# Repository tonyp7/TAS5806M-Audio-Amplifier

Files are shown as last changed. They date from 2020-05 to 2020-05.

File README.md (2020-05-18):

# TAS5806M Audio Amplifier

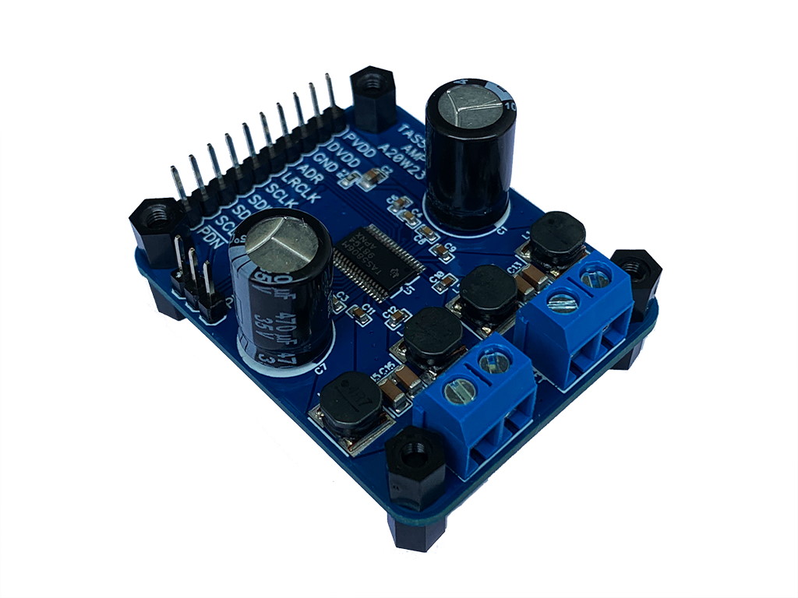
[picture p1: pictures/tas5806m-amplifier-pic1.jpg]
Amplifier board


This repository contains hardware to create a fully fledged TAS5806M 23-W, I2S digital Input, stereo, closed-loop Class-D audio
amplifier.
In addition, it contains example software for Espressif's ESP32 to create a bluetooth audio speaker. Any micro-controller capable of I2S and I2C will be able to control the board, ESP32 is picked here due to its popularity and large documentation.

# Repository structure

* hardware: contains the PCB, schematics and BOM for the physical audio amplfiier board
* software: contains code examples to interface with the board

# License

Hardware and software is free and open source, published under the MIT license.

# Compatibility with TAS5805M

Both amplifiers are the same but in different packages allowing for different maximum power output. They share the same I2C interface and registers and as such the code included in this repository is compatible with TAS5805M audio amplifier. [See here the comment from TI on this topic](http://e2e.ti.com/support/audio/f/6/t/812496?TAS5805M-comparing-to-TAS5806M).

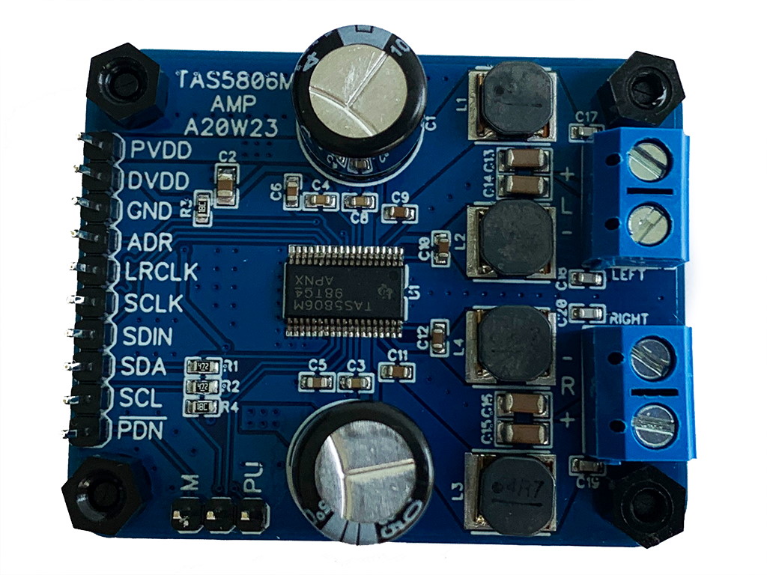
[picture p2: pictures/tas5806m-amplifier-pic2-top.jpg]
Amplifier board top


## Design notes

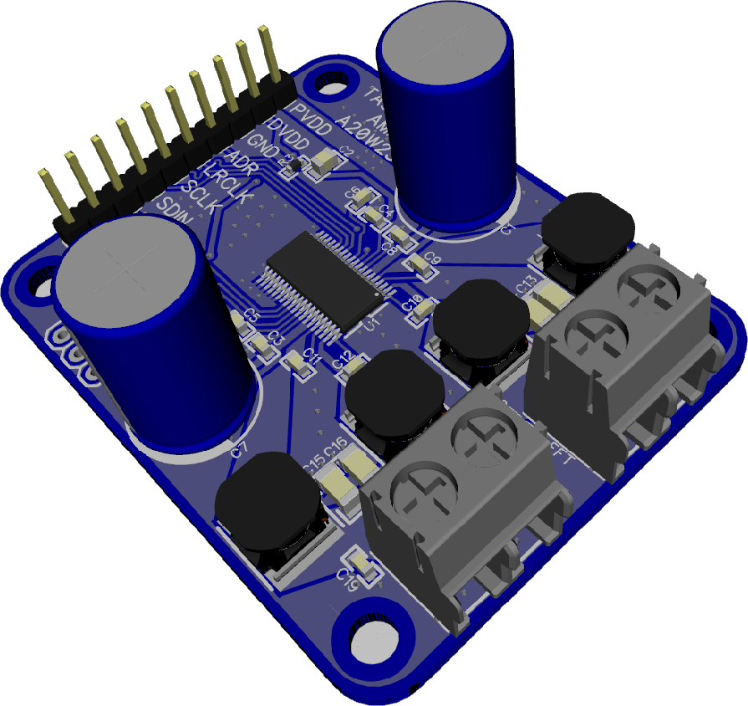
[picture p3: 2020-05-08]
hardware/pcb/3d-pcp-render.png

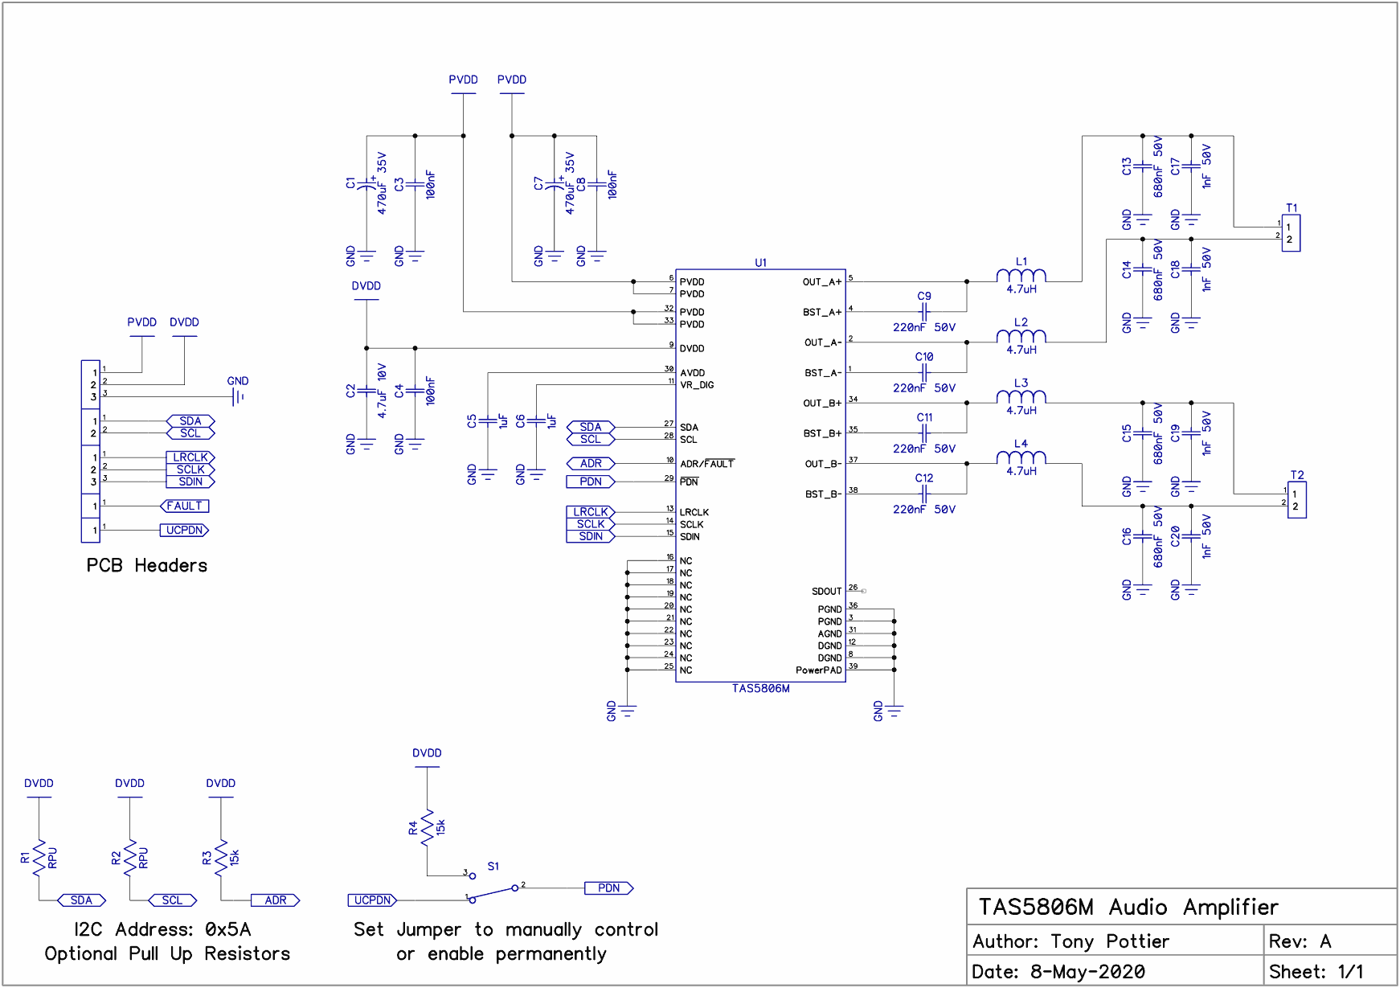
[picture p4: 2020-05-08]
hardware/schematics/tas5806m-schematics.png

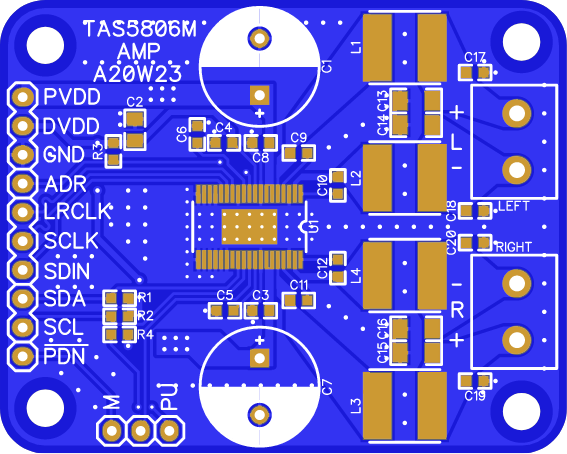
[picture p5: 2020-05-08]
hardware/pcb/pcb-render-top.png

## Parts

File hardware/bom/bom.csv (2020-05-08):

RefDes | Quantity | Manufacturer Part Number | Manufacturer | Description | Mounting | Package
C1, C7 | 2 | EEU-FR1V471 | Panasonic | CAP ALUM 470UF 20% 35V RADIAL | THT
C2 | 1 | CL21A475KPFNNNE | Samsung | CAP CER 4.7UF 10V X5R 0805 | SMT | 0805
C3, C4, C8 | 3 | CC0603KRX7R9BB104 | Yageo | CAP CER 0.1UF 50V X7R 0603 | SMT | 0603
C5, C6 | 2 | CC0603KRX5R6BB105 | Yageo | CAP CER 1UF 10V X5R 0603 | SMT | 0603
C9, C10, C11, C12 | 4 | CC0603KRX7R9BB224 | Yageo | CAP CER 0.22UF 50V X7R 0603 | SMT | 0603
C13, C14, C15, C16 | 4 | CC1206KKX7R9BB684 | Yageo | CAP CER 0.68UF 50V X7R 1206 | SMT | 1206
C17, C18, C19, C20 | 4 | CC0603JRNPO9BN102 | Yageo | CAP CER 1000PF 50V C0G/NPO 0603 | SMT | 0603
L1, L2, L3, L4 | 4 | 1255AY-4R7M=P3 | Murata | FIXED IND 4.7UH 4.5A 27.6 MOHM | SMT
R1, R2 | 2 | RC0603FR-074K7L | Yageo | RES SMD 4.7K OHM 1% 1/10W 0603 | SMT | 0603
R3, R4 | 2 | RC0603FR-0715KL | Yageo | RES SMD 15K OHM 1% 1/10W 0603 | SMT | 0603
T1, T2 | 2 | MC24356-2 | Multicomp | TERMINAL BLOCK EUROSTYLE, 2 POSITION | THT
U1 | 1 | TAS5806MDCPR | Texas Instruments | IC AMP D MONO/STER 45W 38HTSSOP | SMT | TSSOP38

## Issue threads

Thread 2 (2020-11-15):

TAS5805M

tjacobs, 2020-11-15:
Hi again Tony,

Thanks for the response last time on your TAS5805M project.

I have an issue with my TAS5805M based project - the amp works fine, when it works; but often, it doesn't start up correctly.

When it doesn't work, it's detected via I2C fine, and I'm sending it the data fine, but no sound comes out. But - I've found that when I short pin 25 (BST_A+) to ground briefly, it starts playing! This fixes it most every time. And if not I just do it again and it does. This happens on three different revisions of the PCB I've done. I've had to connect that pin to a button that the user can press to make the thing start working. But I don't want that to be the solution. 👎 :-)  I could connect that pin to a FET to drive it low from the MCU on startup, but I don't really want that to be the solution either. I'm using the recommended 4x 0.22uF ("CAP CER 0.22UF 16V X7R 0603") as the boost capacitors, close to the chip.

Any ideas why the amp would do this? Is it not getting that voltage boosted up enough do drive the internal output FETs? Or is it getting into some broken state that is fixed by shorting that, that resets it?

I noticed that when it's playing fine, that pin is at 10.3V (I run the amp on 13V), and when it's stopped, it's at 4.5V. And most importantly, when I'm feeding the amp data and it should be playing but isn't, that pin stays at 4.5V.

Spec sheet just says put capacitors there:
https://www.ti.com/lit/ds/symlink/tas5805m.pdf

tonyp7, 2020-11-16:
To be honest I did have the kind of problems you mention on the TAS5805M where sometimes the sound didnt start. I would just reset the board but I have not tried to short one of the BOOST trace.

I assume the chip is just very picky compared to some other amps. You should definitely read the error register because there should be something in there. Check 70h to 74h you should see a pin set.

For what it's worth, I haven't had an issue with the TAS5806M. Maybe this chip is more mature and less prone to this. I think the layout plays a big role too.

tjacobs, 2020-11-18:
ooh, ok, i'll check the error register, thanks

ah, ok, i'll have to spin yet another board for the 06................

tjacobs, 2020-11-19:
Are you kidding me! Yes it looks like basically you have to clear analog faults on startup, as most if the time it starts up in a both channels overcurrent error; perhaps something to do with how it detects it as power is applied or caps are charging.

https://www.ti.com/lit/ds/symlink/tas5805m.pdf
i2c_read: 0x70:
I got value 3 (= Left channel over current fault + Right channel over current fault)

added:
    // Must clear overcurrent faults on startup
    i2c_write(0x78, 1 << 7);
    if (i2c_read(0x70))printf("Fault starting speaker amp.\n");

And it took it from not working state to working! Yay. Thanks so much!

tonyp7, 2020-11-19:
Thanks for sharing the solution!

Closed 2020-11-19.

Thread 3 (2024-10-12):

Sharing of project files - To adapt for TAS5828M

Glider95, 2024-10-12:
Hello !

I would be interested in your project and would like to swap the TAS5806M with the TAS5828M (32 pin).
Would you still have the project files (KiCad?) so I could adapt?

Cheers,

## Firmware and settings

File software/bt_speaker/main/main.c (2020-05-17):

/*
Copyright (c) 2020 Tony Pottier

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
@author Tony Pottier
@brief this is a modified "a2dp_sink" bluetooth ESP32 speaker example from Espressif.

The changes simply include initializing the audio amp and firing up the tas5806m task

@see https://idyl.io
@see https://github.com/tonyp7/TAS5806M-Audio-Amplifier
*/

// Copyright 2015-2016 Espressif Systems (Shanghai) PTE LTD
//
// Licensed under the Apache License, Version 2.0 (the "License");
// you may not use this file except in compliance with the License.
// You may obtain a copy of the License at

//     http://www.apache.org/licenses/LICENSE-2.0
//
// Unless required by applicable law or agreed to in writing, software
// distributed under the License is distributed on an "AS IS" BASIS,
// WITHOUT WARRANTIES OR CONDITIONS OF ANY KIND, either express or implied.
// See the License for the specific language governing permissions and
// limitations under the License.

#include <stdio.h>
#include <stdlib.h>
#include <unistd.h>
#include <string.h>
#include "freertos/FreeRTOS.h"
#include "freertos/task.h"
#include "nvs.h"
#include "nvs_flash.h"
#include "esp_system.h"
#include "esp_log.h"

#include "esp_bt.h"
#include "bt_app_core.h"
#include "bt_app_av.h"
#include "esp_bt_main.h"
#include "esp_bt_device.h"
#include "esp_gap_bt_api.h"
#include "esp_a2dp_api.h"
#include "esp_avrc_api.h"
#include "driver/i2s.h"


#include "tas5806m.h"




/* event for handler "bt_av_hdl_stack_up */
enum {
    BT_APP_EVT_STACK_UP = 0,
};

/* handler for bluetooth stack enabled events */
static void bt_av_hdl_stack_evt(uint16_t event, void *p_param);





void app_main()
{
    /* Initialize NVS — it is used to store PHY calibration data */
    esp_err_t err = nvs_flash_init();
    if (err == ESP_ERR_NVS_NO_FREE_PAGES || err == ESP_ERR_NVS_NEW_VERSION_FOUND) {
        ESP_ERROR_CHECK(nvs_flash_erase());
        err = nvs_flash_init();
    }
    ESP_ERROR_CHECK(err);

	/* init amp */
	ESP_ERROR_CHECK(audioamp_init());
	/* task for the audio amp */
	xTaskCreate(&audioamp_task, "audioamp_task", 8192, NULL, configMAX_PRIORITIES - 4, NULL);

    i2s_config_t i2s_config = {
#ifdef CONFIG_A2DP_SINK_OUTPUT_INTERNAL_DAC
        .mode = I2S_MODE_MASTER | I2S_MODE_TX | I2S_MODE_DAC_BUILT_IN,
#else
        .mode = I2S_MODE_MASTER | I2S_MODE_TX,                                  // Only TX
#endif
        .sample_rate = 44100,
        .bits_per_sample = 16,
        .channel_format = I2S_CHANNEL_FMT_RIGHT_LEFT,                           //2-channels
        .communication_format = I2S_COMM_FORMAT_I2S_MSB,
        .dma_buf_count = 6,
        .dma_buf_len = 60,
        .intr_alloc_flags = 0,                                                  //Default interrupt priority
        .tx_desc_auto_clear = true                                              //Auto clear tx descriptor on underflow
    };


    i2s_driver_install(0, &i2s_config, 0, NULL);
#ifdef CONFIG_A2DP_SINK_OUTPUT_INTERNAL_DAC
    i2s_set_dac_mode(I2S_DAC_CHANNEL_BOTH_EN);
    i2s_set_pin(0, NULL);
#else
    i2s_pin_config_t pin_config = {
        .bck_io_num = CONFIG_I2S_BCK_PIN,
        .ws_io_num = CONFIG_I2S_LRCK_PIN,
        .data_out_num = CONFIG_I2S_DATA_PIN,
        .data_in_num = -1                                                       //Not used
    };

    i2s_set_pin(0, &pin_config);
#endif


    ESP_ERROR_CHECK(esp_bt_controller_mem_release(ESP_BT_MODE_BLE));

    esp_bt_controller_config_t bt_cfg = BT_CONTROLLER_INIT_CONFIG_DEFAULT();
    if ((err = esp_bt_controller_init(&bt_cfg)) != ESP_OK) {
        ESP_LOGE(BT_AV_TAG, "%s initialize controller failed: %s\n", __func__, esp_err_to_name(err));
        return;
    }

    if ((err = esp_bt_controller_enable(ESP_BT_MODE_CLASSIC_BT)) != ESP_OK) {
        ESP_LOGE(BT_AV_TAG, "%s enable controller failed: %s\n", __func__, esp_err_to_name(err));
        return;
    }

    if ((err = esp_bluedroid_init()) != ESP_OK) {
        ESP_LOGE(BT_AV_TAG, "%s initialize bluedroid failed: %s\n", __func__, esp_err_to_name(err));
        return;
    }

    if ((err = esp_bluedroid_enable()) != ESP_OK) {
        ESP_LOGE(BT_AV_TAG, "%s enable bluedroid failed: %s\n", __func__, esp_err_to_name(err));
        return;
    }

    /* create application task */
    bt_app_task_start_up();

    /* Bluetooth device name, connection mode and profile set up */
    bt_app_work_dispatch(bt_av_hdl_stack_evt, BT_APP_EVT_STACK_UP, NULL, 0, NULL);

#if (CONFIG_BT_SSP_ENABLED == true)
    /* Set default parameters for Secure Simple Pairing */
    esp_bt_sp_param_t param_type = ESP_BT_SP_IOCAP_MODE;
    esp_bt_io_cap_t iocap = ESP_BT_IO_CAP_IO;
    esp_bt_gap_set_security_param(param_type, &iocap, sizeof(uint8_t));
#endif

    /*
     * Set default parameters for Legacy Pairing
     * Use fixed pin code
     */
    esp_bt_pin_type_t pin_type = ESP_BT_PIN_TYPE_FIXED;
    esp_bt_pin_code_t pin_code;
    pin_code[0] = '1';
    pin_code[1] = '2';
    pin_code[2] = '3';
    pin_code[3] = '4';
    esp_bt_gap_set_pin(pin_type, 4, pin_code);
	
	
	
	

	
	
}

void bt_app_gap_cb(esp_bt_gap_cb_event_t event, esp_bt_gap_cb_param_t *param)
{
    switch (event) {
    case ESP_BT_GAP_AUTH_CMPL_EVT: {
        if (param->auth_cmpl.stat == ESP_BT_STATUS_SUCCESS) {
            ESP_LOGI(BT_AV_TAG, "authentication success: %s", param->auth_cmpl.device_name);
            esp_log_buffer_hex(BT_AV_TAG, param->auth_cmpl.bda, ESP_BD_ADDR_LEN);
        } else {
            ESP_LOGE(BT_AV_TAG, "authentication failed, status:%d", param->auth_cmpl.stat);
        }
        break;
    }

#if (CONFIG_BT_SSP_ENABLED == true)
    case ESP_BT_GAP_CFM_REQ_EVT:
        ESP_LOGI(BT_AV_TAG, "ESP_BT_GAP_CFM_REQ_EVT Please compare the numeric value: %d", param->cfm_req.num_val);
        esp_bt_gap_ssp_confirm_reply(param->cfm_req.bda, true);
        break;
    case ESP_BT_GAP_KEY_NOTIF_EVT:
        ESP_LOGI(BT_AV_TAG, "ESP_BT_GAP_KEY_NOTIF_EVT passkey:%d", param->key_notif.passkey);
        break;
    case ESP_BT_GAP_KEY_REQ_EVT:
        ESP_LOGI(BT_AV_TAG, "ESP_BT_GAP_KEY_REQ_EVT Please enter passkey!");
        break;
#endif

    default: {
        ESP_LOGI(BT_AV_TAG, "event: %d", event);
        break;
    }
    }
    return;
}
static void bt_av_hdl_stack_evt(uint16_t event, void *p_param)
{
    ESP_LOGD(BT_AV_TAG, "%s evt %d", __func__, event);
    switch (event) {
    case BT_APP_EVT_STACK_UP: {
        /* set up device name */
        char *dev_name = "ESP_SPEAKER";
        esp_bt_dev_set_device_name(dev_name);

        esp_bt_gap_register_callback(bt_app_gap_cb);
        /* initialize A2DP sink */
        esp_a2d_register_callback(&bt_app_a2d_cb);
        esp_a2d_sink_register_data_callback(bt_app_a2d_data_cb);
        esp_a2d_sink_init();

        /* initialize AVRCP controller */
        esp_avrc_ct_init();
        esp_avrc_ct_register_callback(bt_app_rc_ct_cb);

        /* set discoverable and connectable mode, wait to be connected */
        esp_bt_gap_set_scan_mode(ESP_BT_SCAN_MODE_CONNECTABLE_DISCOVERABLE);
        break;
    }
    default:
        ESP_LOGE(BT_AV_TAG, "%s unhandled evt %d", __func__, event);
        break;
    }
}

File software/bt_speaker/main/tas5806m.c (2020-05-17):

/*
Copyright (c) 2020 Tony Pottier

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
@author Tony Pottier
@brief esp-idf compatible code to communicate with a TAS5806M audio amplifier
@see https://idyl.io
@see https://github.com/tonyp7/TAS5806M-Audio-Amplifier
*/

#include <stdio.h>
#include <stdlib.h>
#include <unistd.h>
#include <string.h>
#include "freertos/FreeRTOS.h"
#include "freertos/task.h"
#include "nvs.h"
#include "nvs_flash.h"
#include "esp_system.h"
#include "esp_log.h"

#include "esp_bt.h"
#include "bt_app_core.h"
#include "bt_app_av.h"
#include "esp_bt_main.h"
#include "esp_bt_device.h"
#include "esp_gap_bt_api.h"
#include "esp_a2dp_api.h"
#include "esp_avrc_api.h"
#include "driver/i2s.h"


#include "driver/i2c.h"

#include "tas5806m.h"


static SemaphoreHandle_t audio_ready_mutex = NULL;
static const char TAS5806M_TAG[] = "tas5806m";



esp_err_t i2c_master_init(){
	esp_err_t ret;
    int i2c_master_port = I2C_MASTER_NUM;
    i2c_config_t conf;
    conf.mode = I2C_MODE_MASTER;
    conf.sda_io_num = I2C_MASTER_SDA_IO;
    conf.sda_pullup_en = GPIO_PULLUP_DISABLE;
    conf.scl_io_num = I2C_MASTER_SCL_IO;
    conf.scl_pullup_en = GPIO_PULLUP_DISABLE;
    conf.master.clk_speed = I2C_MASTER_FREQ_HZ;
    ret = i2c_param_config(i2c_master_port, &conf);
    if(ret == ESP_OK){
    	return i2c_driver_install(i2c_master_port, conf.mode, I2C_MASTER_RX_BUF_DISABLE, I2C_MASTER_TX_BUF_DISABLE, 0);
    }
    return ret;
}

esp_err_t unlock_audioamp(){
	xSemaphoreGive( audio_ready_mutex );
	return ESP_OK;
}


esp_err_t tas5806m_read(uint8_t register_name, uint8_t* data_rd, size_t size){
    if (size == 0) {
        return ESP_OK;
    }
    i2c_cmd_handle_t cmd = i2c_cmd_link_create();
    i2c_master_start(cmd);
    i2c_master_write_byte(cmd, ( TAS5806M_ADDRESS << 1 ) | READ_BIT, ACK_CHECK_EN);
    i2c_master_write_byte(cmd, register_name, ACK_CHECK_EN);
    if (size > 1) {
        i2c_master_read(cmd, data_rd, size - 1, ACK_VAL);
    }
    i2c_master_read_byte(cmd, data_rd + size - 1, NACK_VAL);
    i2c_master_stop(cmd);
    esp_err_t ret = i2c_master_cmd_begin(I2C_TAS5806M_MASTER_NUM, cmd, 1000 / portTICK_RATE_MS);
    i2c_cmd_link_delete(cmd);
    return ret;
}

esp_err_t tas5806m_write_byte(uint8_t register_name, uint8_t value){
	esp_err_t ret;
	i2c_cmd_handle_t cmd = i2c_cmd_link_create();
	i2c_master_start(cmd);
	i2c_master_write_byte(cmd, TAS5806M_ADDRESS << 1 | WRITE_BIT, ACK_CHECK_EN);
	i2c_master_write_byte(cmd, register_name, ACK_CHECK_EN);
	i2c_master_write_byte(cmd, value, ACK_CHECK_EN);
	i2c_master_stop(cmd);
	ret = i2c_master_cmd_begin(I2C_TAS5806M_MASTER_NUM, cmd, 1000 / portTICK_RATE_MS);
	i2c_cmd_link_delete(cmd);

	return ret;
}


esp_err_t audioamp_init(){
	
	esp_err_t ret;
	
	/* audio_ready_mutex */
	audio_ready_mutex = xSemaphoreCreateMutex();
	
	/* Register the PDN pin as output and write 1 to enable the TAS chip */
	gpio_config_t io_conf;
    io_conf.intr_type = GPIO_PIN_INTR_DISABLE;
    io_conf.mode = GPIO_MODE_OUTPUT;
    io_conf.pin_bit_mask = TAS5806M_GPIO_PDN_MASK;
    io_conf.pull_down_en = 0;
    io_conf.pull_up_en = 0;
    gpio_config(&io_conf);
	gpio_set_level(TAS5806M_GPIO_PDN, 1);

	/* initialize I2C to drive the TAS5806M */
	ret = i2c_master_init();
	if(ret != ESP_OK){
		ESP_LOGE(TAS5806M_TAG, "I2C could not be initialized.");
		return ret;
	}
	
	
	if( xSemaphoreTake( audio_ready_mutex, portMAX_DELAY ) == pdTRUE ) {
		ESP_LOGI(TAS5806M_TAG, "Locked audio_ready_mutex until I2S sound is ready");
	}
	
	return ESP_OK;
}

void audioamp_task(void *pvParameter){


	for(;;){
		
		if( xSemaphoreTake( audio_ready_mutex, portMAX_DELAY ) == pdTRUE ) {
			
			/* sound is ready */
			ESP_LOGI(TAS5806M_TAG, "I2S is ready, setup of the audio amp begin");
			vTaskDelay(1000 / portTICK_RATE_MS);
			
			/* set PDN to 1 */
			gpio_set_level(TAS5806M_GPIO_PDN, 1);
			vTaskDelay(100 / portTICK_RATE_MS);
			
			ESP_LOGI(TAS5806M_TAG, "Setting to HI Z");
			ESP_ERROR_CHECK(tas5806m_write_byte(0x03, 0x02));
			vTaskDelay(100 / portTICK_RATE_MS);
			
			ESP_LOGI(TAS5806M_TAG, "Setting to PLAY");
			ESP_ERROR_CHECK(tas5806m_write_byte(0x03, 0x03));
			
			vTaskDelay(100 / portTICK_RATE_MS);
			
			int ret;
			uint8_t h70 = 0, h71 = 0, h72 = 0;
			i2c_cmd_handle_t cmd = i2c_cmd_link_create();
			i2c_master_start(cmd);
			i2c_master_write_byte(cmd, TAS5806M_ADDRESS << 1 | WRITE_BIT, ACK_CHECK_EN);
			i2c_master_write_byte(cmd, 0x70, ACK_CHECK_EN);
			i2c_master_stop(cmd);
			ret = i2c_master_cmd_begin(I2C_TAS5806M_MASTER_NUM, cmd, 1000 / portTICK_RATE_MS);
			i2c_cmd_link_delete(cmd);
			if (ret != ESP_OK) {
				ESP_LOGE(TAS5806M_TAG, "I2C ERROR");
			}
			vTaskDelay(1 / portTICK_RATE_MS);
			cmd = i2c_cmd_link_create();
			i2c_master_start(cmd);
			i2c_master_write_byte(cmd, TAS5806M_ADDRESS << 1 | READ_BIT, ACK_CHECK_EN);
			i2c_master_read_byte(cmd, &h70, ACK_VAL);
			i2c_master_read_byte(cmd, &h71, ACK_VAL);
			i2c_master_read_byte(cmd, &h72, NACK_VAL);
			i2c_master_stop(cmd);
			ret = i2c_master_cmd_begin(I2C_TAS5806M_MASTER_NUM , cmd, 1000 / portTICK_RATE_MS);
			i2c_cmd_link_delete(cmd);
			
			ESP_LOGI(TAS5806M_TAG, "0x70 Register: %d", h70);
			ESP_LOGI(TAS5806M_TAG, "0x71 Register: %d", h71);
			ESP_LOGI(TAS5806M_TAG, "0x72 Register: %d", h72);
			
			
		}
		vTaskDelay(1000 / portTICK_RATE_MS);
		

		
	}
}

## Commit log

2020-05-08 Create pcb-render-top.png
    courtesy of tracespace.io
2020-05-17 added pic of board
2020-06-18 added gerber
    [Through.drl, tas5806m.Board.gbr, tas5806m.BoardOutline.gbr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]
